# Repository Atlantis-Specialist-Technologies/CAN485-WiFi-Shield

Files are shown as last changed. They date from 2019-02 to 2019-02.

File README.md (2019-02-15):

SparkFun AST-CAN485 WiFi Shield
========================================

SparkFun AST-CAN485 WiFi Shield

[*SparkFun AST-CAN485 WiFi Shield (14597)*](https://www.sparkfun.com/products/14597)

The [AST-CAN485 Dev Board](https://www.sparkfun.com/products/14483) brings CAN (Control Area Network) and RS485 to a small, Pro Mini form factor with the ability to interface to 24V input and outputs. When looking to save space, losing the communication cable is one of the best options as well. The SparkFun AST-CAN485 WiFi Shield does just that. With Screw terminal connectors for RS-485 and a U.FL connector, this board supplies solid solutions for working wirelessly in automation, an environment famous for being noisy and unforgiving to electronics. 

The board uses Espressif's ESP8266, a widely used chip in IoT, for wireless communication. The AST-CAN485 WiFi Shield possesses a PCB trace antenna as well as an on-board U.FL connector which allows for external WiFi antennas in situations where more signal strength or distance is needed. An FTDI header is provided as well for working with the ESP8266.

Repository Contents
-------------------

* **/Documentation** - Data sheets, additional product information
* **/Examples/BasicSerial** - Enclosure files 
* **/Hardware** - Eagle design files (.brd, .sch)

Documentation
--------------
* **[Hookup Guide](https://learn.sparkfun.com/tutorials/ast-can485-wifi-shield-hookup-guide)** - Basic hookup guide for the SparkFun AST-CAN485 WiFi Shield.
* **[SparkFun Fritzing repo](https://github.com/sparkfun/Fritzing_Parts)** - Fritzing diagrams for SparkFun products.

License Information
-------------------

This product is _**open source**_! 

Please review the LICENSE.md file for license information. 

If you have any questions or concerns on licensing, please contact techsupport@sparkfun.com.

Distributed as-is; no warranty is given.

- Your friends at SparkFun, in collaboration with Atlantis Specialist Technologies

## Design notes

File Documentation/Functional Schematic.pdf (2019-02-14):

CAN485

AT90CAN128 | ESP8266 Level Shift | SW²

TX
TX | RX

RX

Serial 0

TX

RX

Serial 1

RS 485
Transceiver
RS485
SPI | SPI
D6 | ESP RST

Wifi Shield

3.3V FTDI

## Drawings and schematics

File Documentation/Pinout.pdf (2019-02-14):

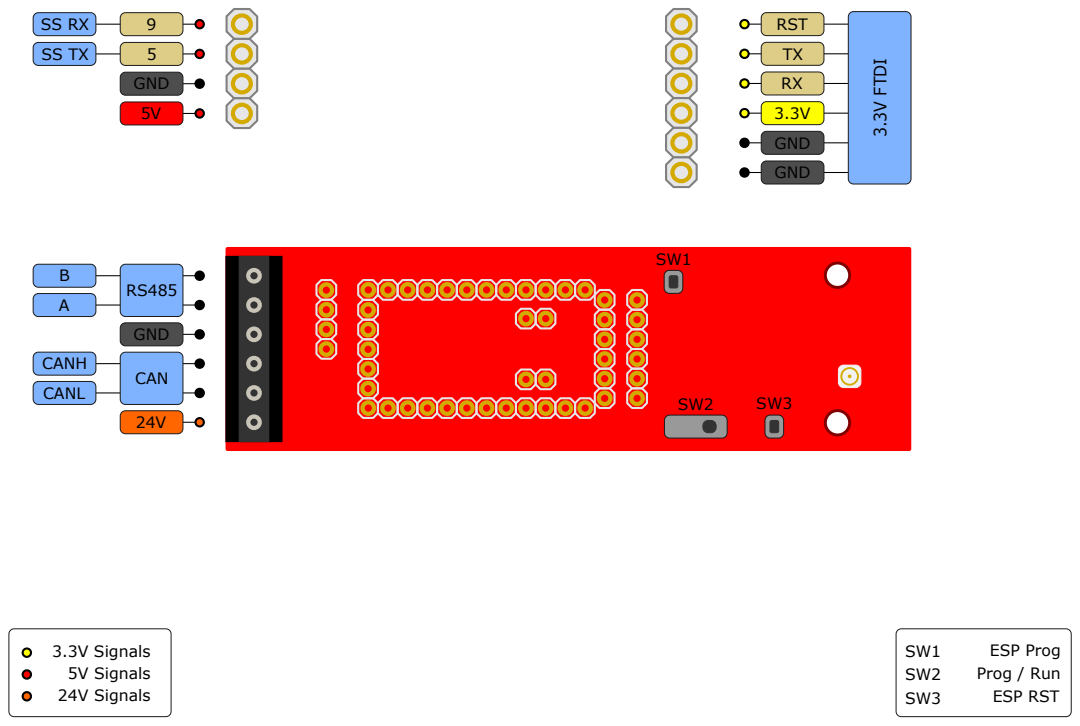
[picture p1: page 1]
GND; CAN; CANL; CANH AB; RST; 3.3V FTDI; 5V Signals 24V Signals; 3.3V Signals; Prog / Run ESP RST; ESP Prog

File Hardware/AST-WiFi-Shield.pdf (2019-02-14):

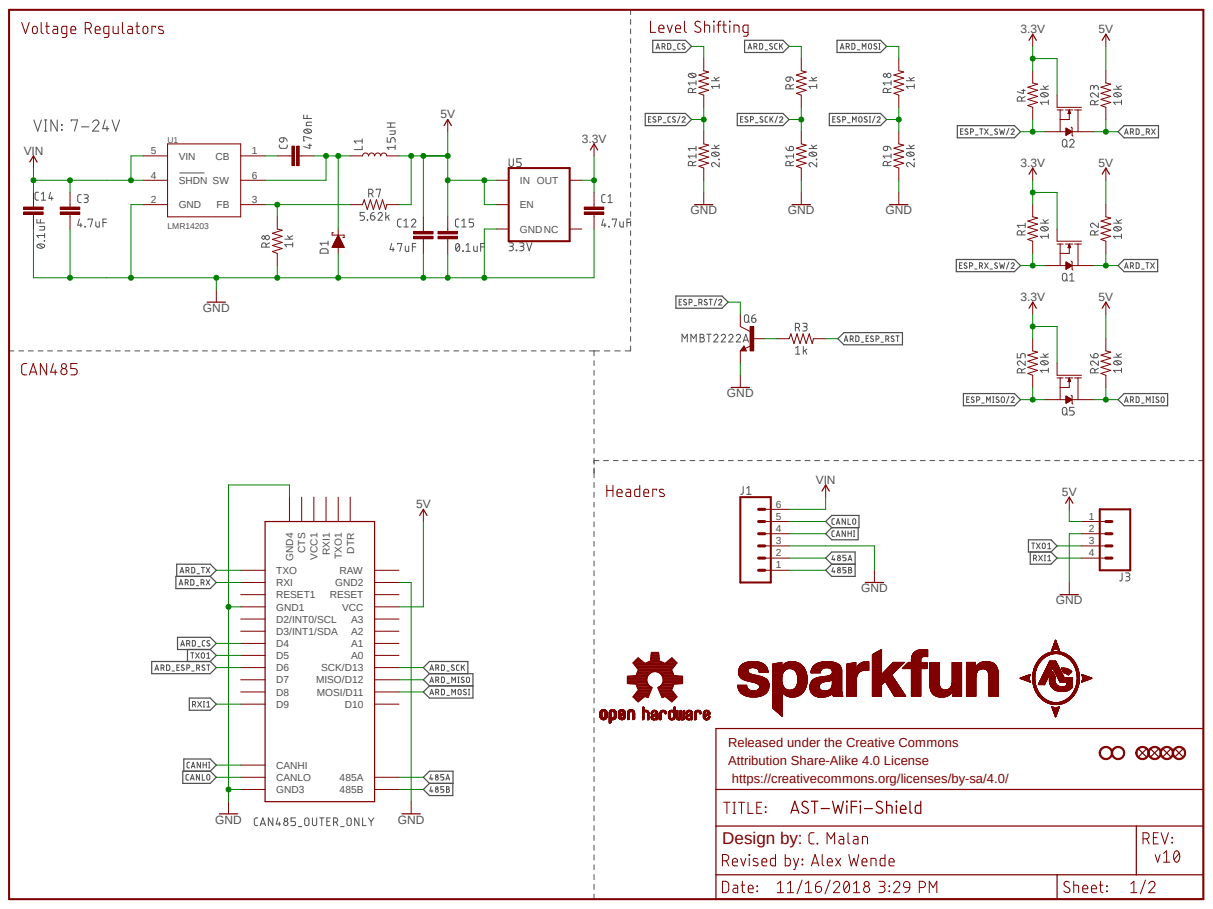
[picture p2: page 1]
LMR14203 U1; GND; VIN; 3 GND 2; SHDN 4; 6 VIN 5; INGNDOUT EN; A0A1A2A3 CANHI CANLOCTS D2/INT0/SCL D3/INT1/SDA D4 D5 D6 D7 D8 D9; D10DTR GND1; GND2 GND3GND⁴; MISO/D12 MOSI/D11 RAW; RESET1; RESET RXI; RXI1 SCK/D13 TXO; TXO¹ VCC VCC¹; Design by:

6 Released under the Creative Commons

Attribution Share-Alike 4.0 License
https://creativecommons.org/licenses/by-sa/4.0/

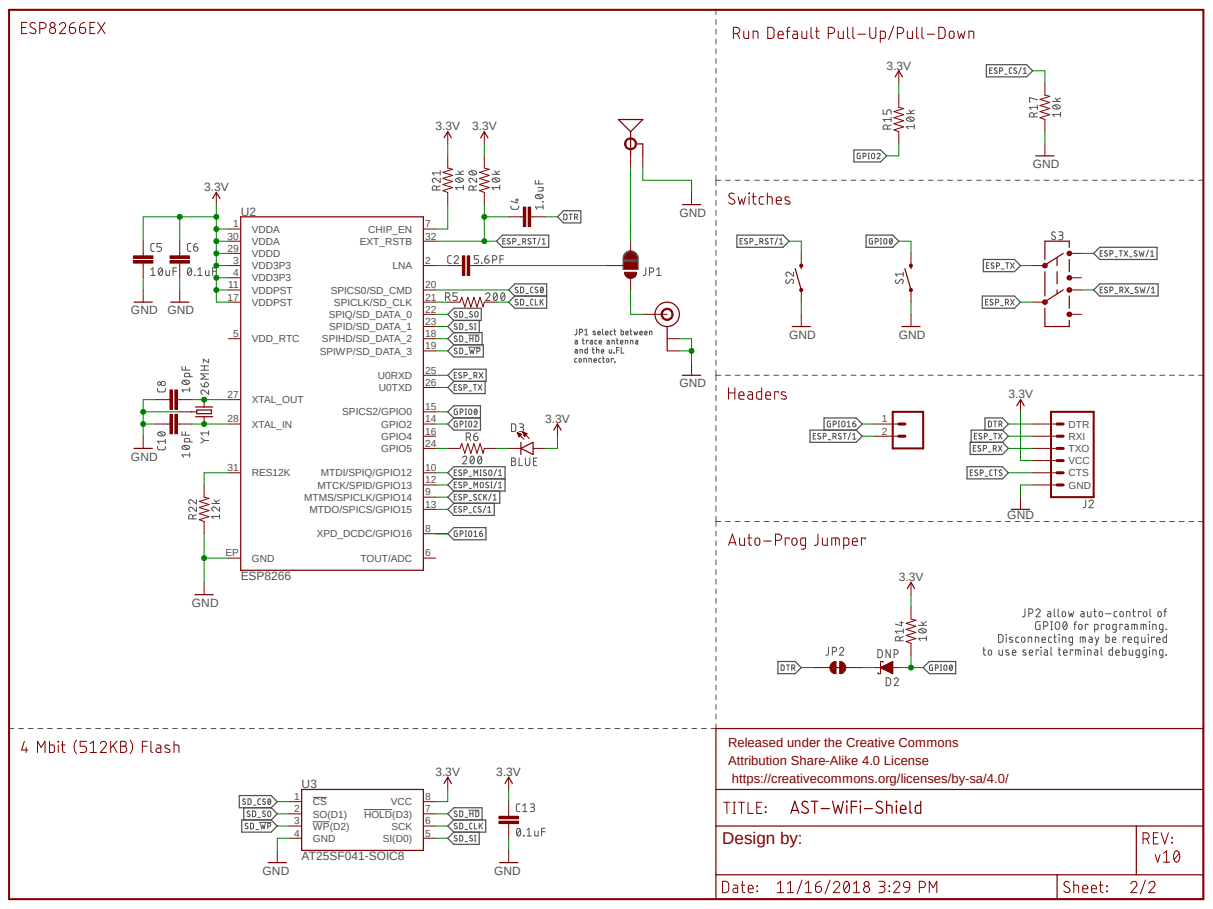
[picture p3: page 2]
ESP8266; GND; GND GND; AT25SF041-SOIC8; VDDA 1; LNA; 2 VDD3P3 3; VDD3P3 4; VDD_RTC 5; TOUT/ADC; CHIP_EN; XPD_DCDC/GPIO16; 8 MTMS/SPICLK/GPIO14; 9 MTDI/SPIQ/GPIO12; 10 VDDPST 11; MTCK/SPID/GPIO13; 12 MTDO/SPICS/GPIO15; 13 GPIO2; 14 SPICS2/GPIO0; 15 GPIO4; 16 VDDPST 17; SPIHD/SD_DATA_2; 18 SPIWP/SD_DATA_3; 19 SPICS0/SD_CMD; 20 SPICLK/SD_CLK; 21 SPIQ/SD_DATA_0; 22 SPID/SD_DATA_1; 23 GPIO5; 24 U0RXD; 25 U0TXD; 26 XTAL_OUT 27; XTAL_IN 28; VDDD 29; VDDA 30; RES12K 31; EXT_RSTB; 32 GND EP; GND 4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

Released under the Creative Commons
Attribution Share-Alike 4.0 License
https://creativecommons.org/licenses/by-sa/4.0/

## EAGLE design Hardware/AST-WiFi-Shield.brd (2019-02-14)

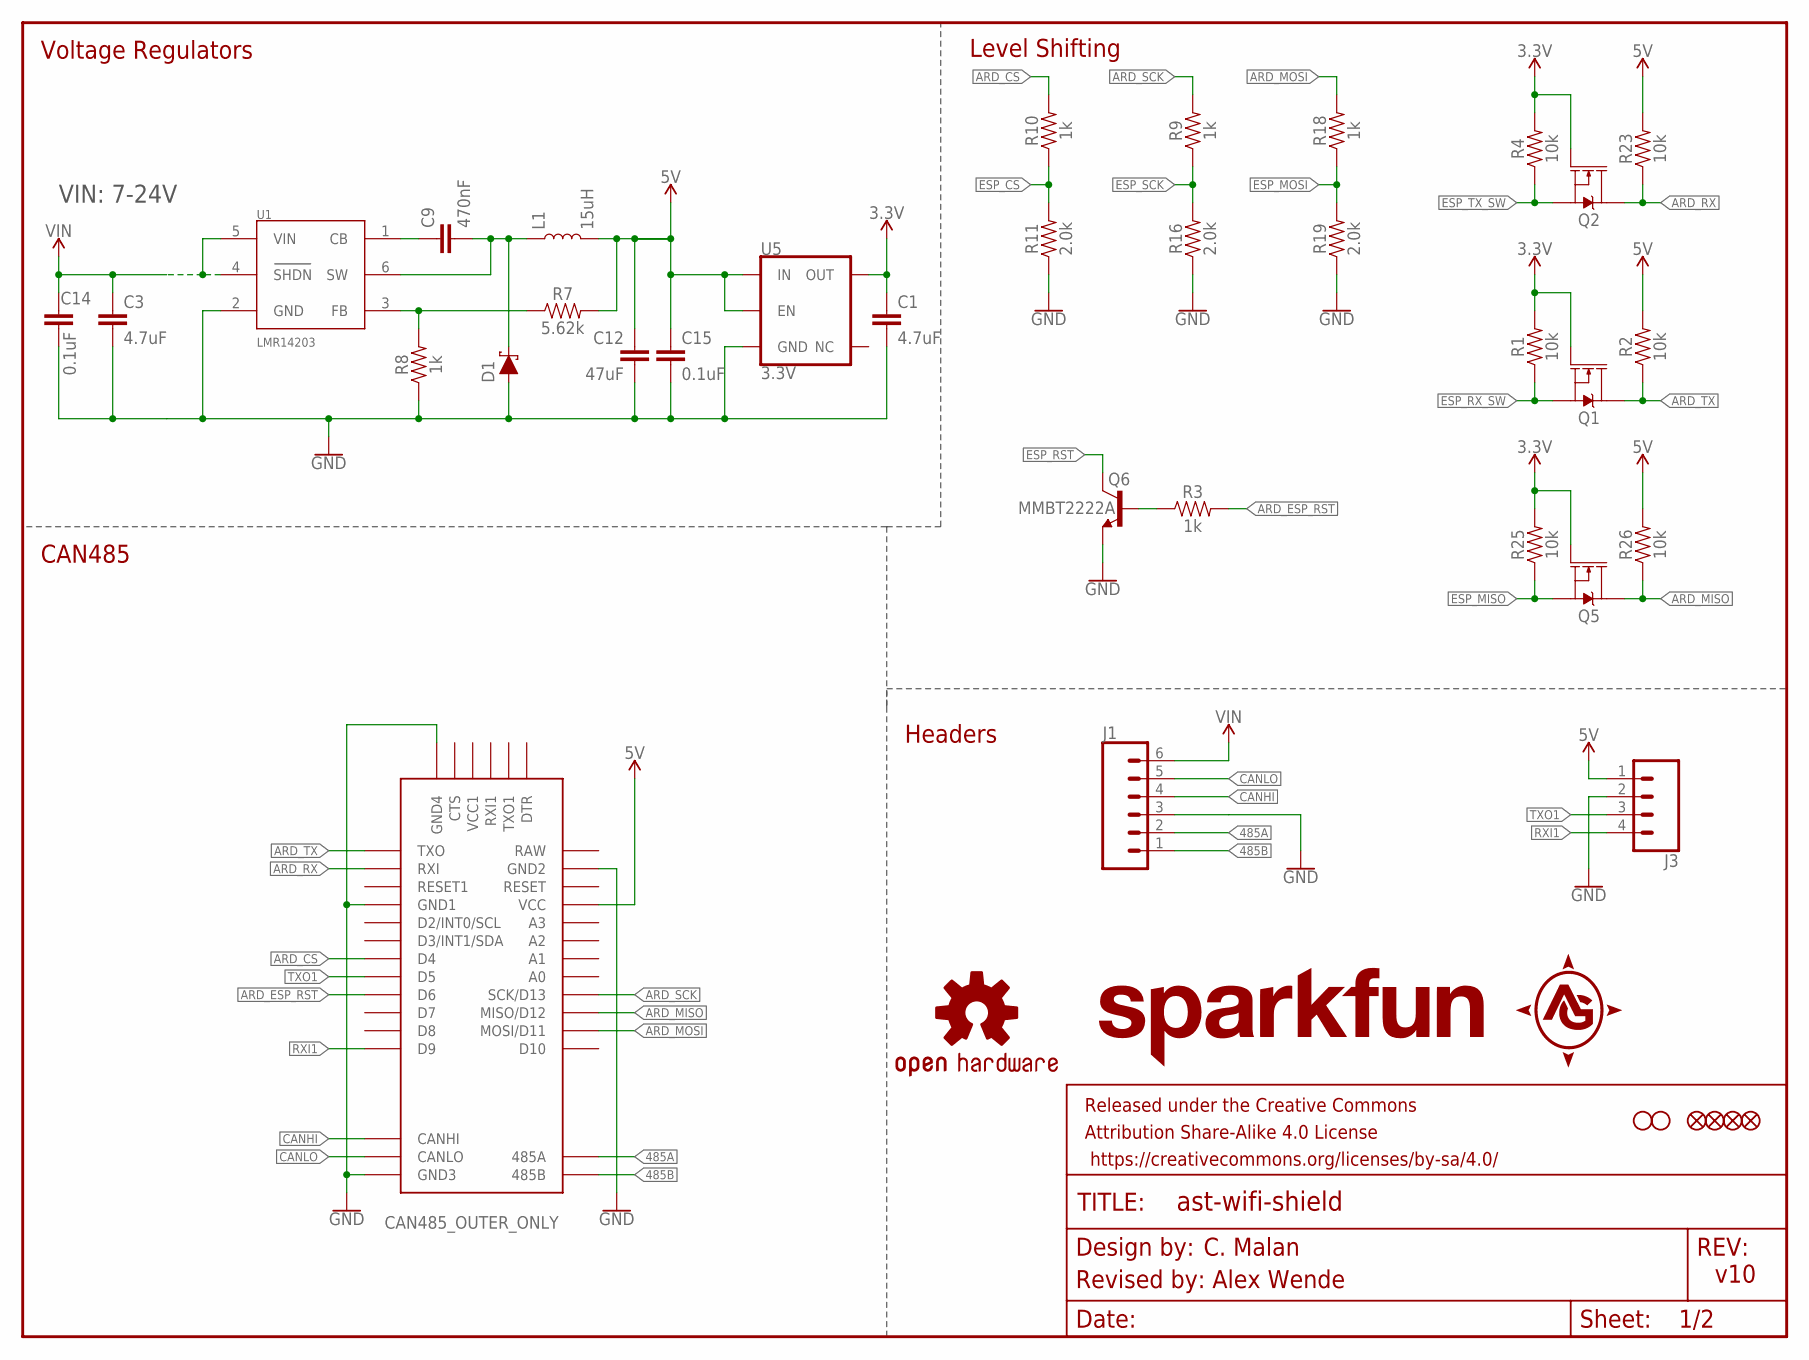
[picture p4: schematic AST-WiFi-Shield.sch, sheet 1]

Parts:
C1, C3: 4.7uF; 0603
C9: 470nF; 0603
C12: 47uF; 0805
C14, C15: 0.1uF; 0603
D1: DIODE-SCHOTTKY-MSS1P6-M3/89A; DIODE-MICRO-SMP
FD1, FD2, FD3, FD4: FIDUCIALUFIDUCIAL; FIDUCIAL-MICRO
FRAME2: FRAME-LETTER; CREATIVE_COMMONS
H1, H2: STAND-OFF
J1: CONN_063.5MM-6; SCREWTERMINAL-3.5MM-6
J3: CONN_04LOCK; 1X04_LOCK
L1: 15uH; INDUCTOR_LQH32
LOGO1: OSHW-LOGOS; OSHW-LOGO-S
LOGO2: SFE_LOGO_NAME.2_INCH; SFE_LOGO_NAME_.2
Q1, Q2, Q5: 220mA/50V/3.5Ω; SOT23-3
Q6: MMBT2222A; SOT23-3@1
R1, R2, R4, R23, R25, R26: 10k; 0603
R3, R8, R9, R10, R18: 1k; 0603
R7: 5.62k; 0603
R11, R16, R19: 2.0k; 0603
U1: LMR14203; SOT23-6
U5: 3.3V; SOT23-5
U$2: CAN485_OUTER_ONLY

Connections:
3.3V: C1.1, Q1.1 (G), Q2.1 (G), Q5.1 (G), R1.2, R4.2, R25.2, U5.5 (OUT); also elsewhere on the board
5V: C12.1, C15.1, J3.1, L1.P$2 (2), R2.2, R7.2, R23.2, R26.2, U5.1 (IN), U5.3 (EN), U$2.VCC
485A: J1.2, U$2.485A
485B: J1.1, U$2.485B
ARD_CS: R10.2, U$2.4 (D4)
ARD_ESP_RST: R3.2, U$2.6 (D6)
ARD_MISO: Q5.3 (D), R26.1, U$2.12 (MISO/D12)
ARD_MOSI: R18.2, U$2.11 (MOSI/D11)
ARD_RX: Q2.3 (D), R23.1, U$2.RXI
ARD_SCK: R9.2, U$2.13 (SCK/D13)
ARD_TX: Q1.3 (D), R2.1, U$2.TXO
CANHI: J1.4, U$2.CANHI
CANLO: J1.5, U$2.CANLO
ESP_CS: R10.1, R11.2; also elsewhere on the board
ESP_MISO: Q5.2 (S), R25.1; also elsewhere on the board
ESP_MOSI: R18.1, R19.2; also elsewhere on the board
ESP_RST: Q6.3 (C); also elsewhere on the board
ESP_RX_SW: Q1.2 (S), R1.1; also elsewhere on the board
ESP_SCK: R9.1, R16.2; also elsewhere on the board
ESP_TX_SW: Q2.2 (S), R4.1; also elsewhere on the board
GND: C1.2, C3.2, C12.2, C14.2, C15.2, D1.A, J1.3, J3.2, Q6.2 (E), R8.1, R11.1, R16.1, R19.1, U1.2 (GND), U5.2 (GND), U$2.GND1, U$2.GND2, U$2.GND3, U$2.GND4; also elsewhere on the board
unnamed: C9.1, U1.1 (CB)
unnamed: R7.1, R8.2, U1.3 (FB)
unnamed: Q6.1 (B), R3.1
RXI1: J3.4, U$2.9 (D9)
TXO1: J3.3, U$2.5 (D5)
VIN: C3.1, C14.1, J1.6, U1.4 (SHDN), U1.5 (VIN)
VSW: C9.2, D1.C, L1.P$1 (1), U1.6 (SW)

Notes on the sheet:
Headers
Voltage Regulators
Level Shifting
C. Malan
Revised by: Alex Wende
CAN485
v10
VIN: 7-24V

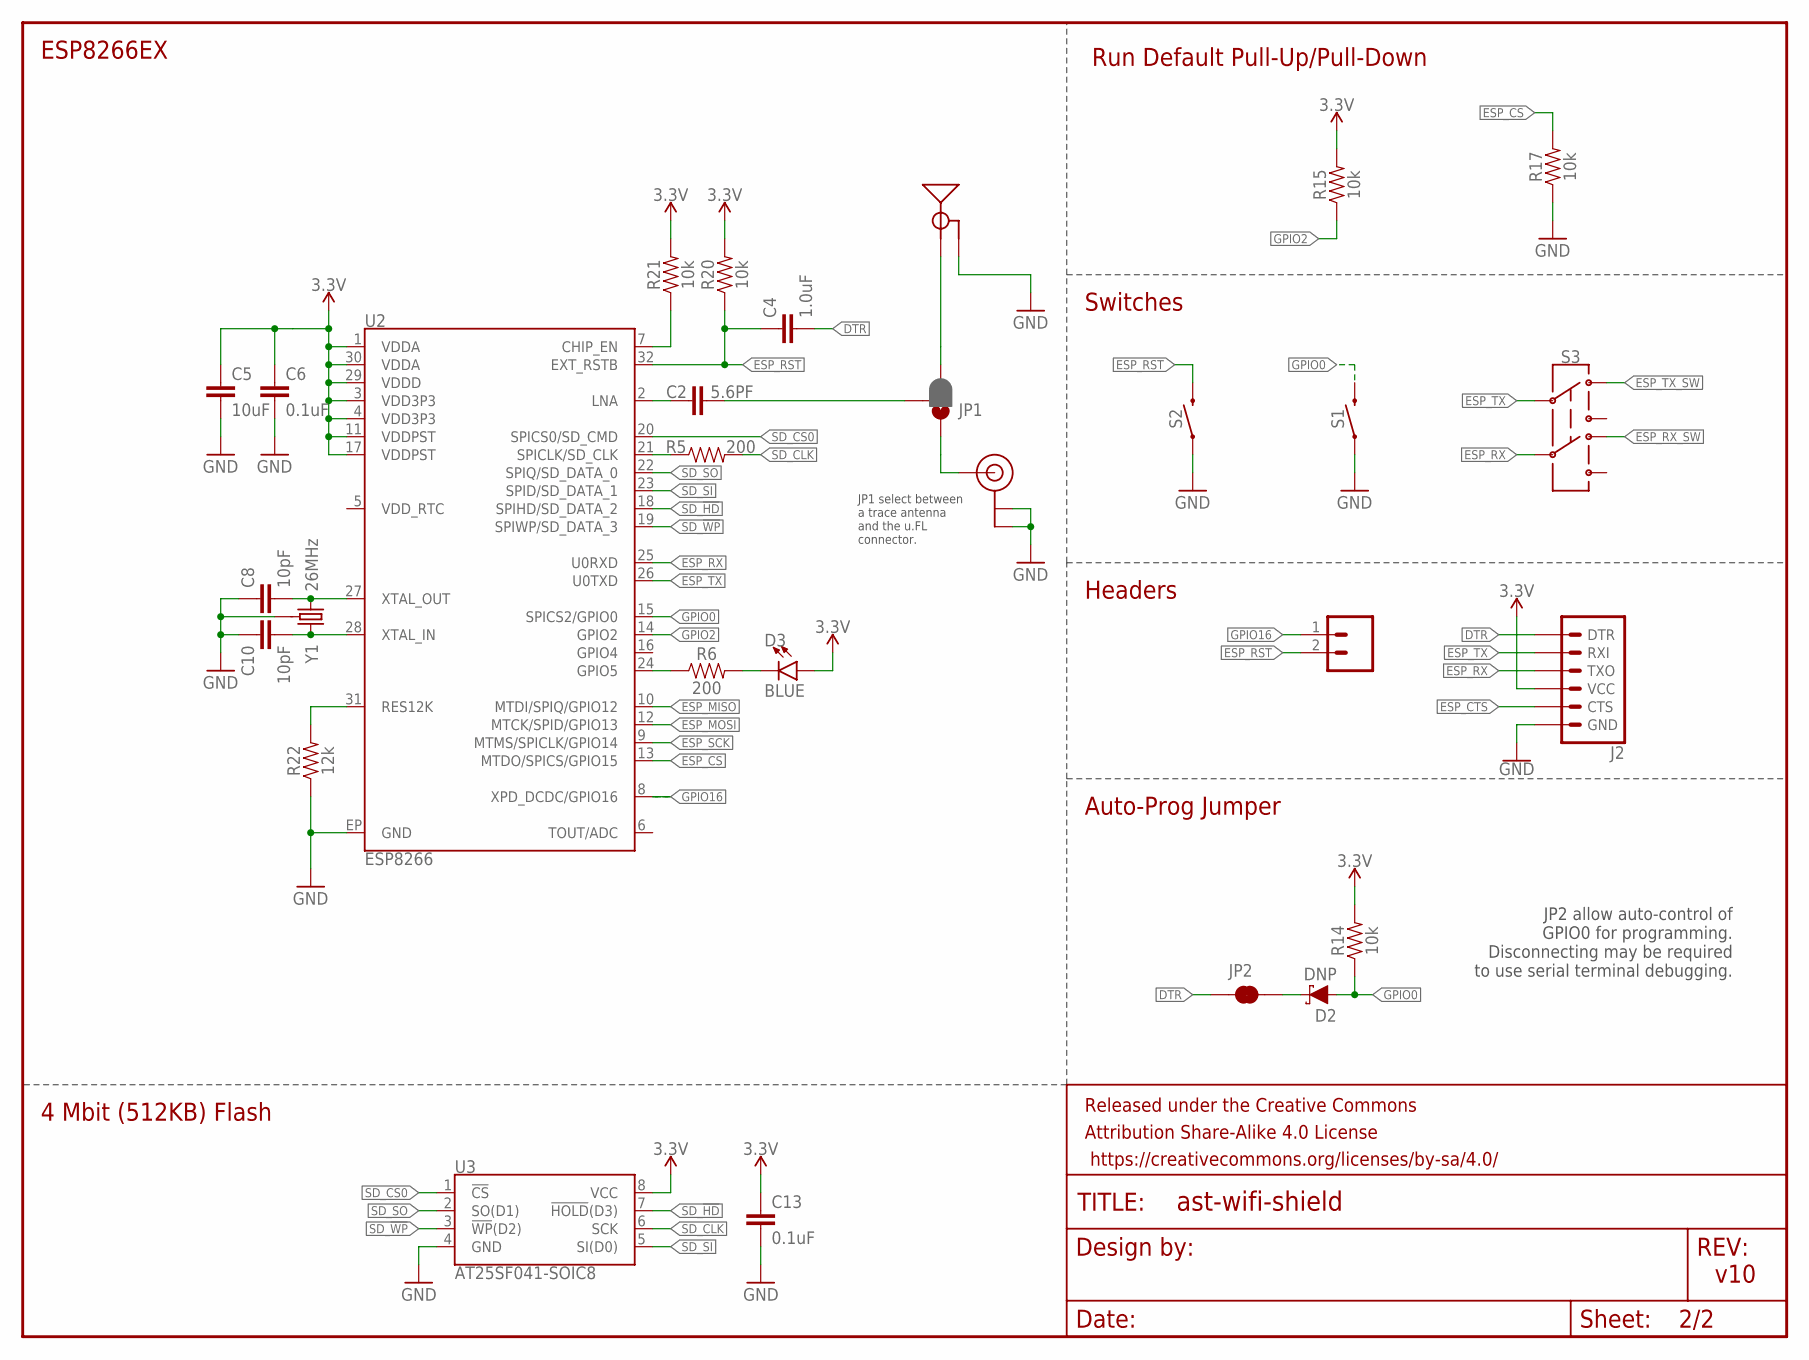
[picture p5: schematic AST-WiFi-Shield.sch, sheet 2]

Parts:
C2: 5.6PF; 0603
C4: 1.0uF; 0603
C5: 10uF; 0603
C6, C13: 0.1uF; 0603
C8, C10: 10pF; 0603
D2: DNP; SOD-323
D3: BLUE; LED-0603
E1: ANTENNATRACE; TRACE_ANTENNA_2.4GHZ_25.7MM
E2: U.FL
FRAME3: FRAME-LETTERNO_PACKAGE; DUMMY
J2: 6_PIN_SERIAL_TARGETLOCK; 1X06_LOCK
JP1: JUMPER-SMT_3_1-NC_PASTE_NO-SILK; SMT-JUMPER_3_1-NC_PASTE_NO-SILK
JP2: JUMPER-SMT_2_NC_TRACE_NO-SILK; SMT-JUMPER_2_NC_TRACE_NO-SILK
R5, R6: 200; 0603
R14, R15, R17, R20, R21: 10k; 0603
R22: 12k; 0603
S1, S2: MOMENTARY-SWITCH-SPST-SMD-4.6X2.8MM; TACTILE_SWITCH_SMD_4.6X2.8MM
S3: SWITCH-DPDT-SMD-JS202011JCQN; SWITCH_DPDT_SMD_JS202011JCQN
SJ2: SLEEP-PTH; 1X02_NO_SILK
U2: ESP8266; QFN32
U3: AT25SF041-SOIC8; SO08
Y1: 26MHz; CRYSTAL-SMD-3.2X2.5

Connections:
3.3V: C5.1, C6.1, C13.1, D3.A, J2.4 (VCC), R14.2, R15.2, R20.2, R21.2, U2.1 (VDDA), U2.3 (VDD3P3), U2.4 (VDD3P3), U2.11 (VDDPST), U2.17 (VDDPST), U2.29 (VDDD), U2.30 (VDDA), U3.8 (VCC); also elsewhere on the board
ANT: E2.FEED (SIGNAL), JP1.1
CHIP_EN: R21.1, U2.7 (CHIP_EN)
DTR: C4.2, J2.1 (DTR), JP2.1
ESP_CS: R17.2, U2.13 (MTDO/SPICS/GPIO15); also elsewhere on the board
ESP_CTS: J2.5 (CTS)
ESP_MISO: U2.10 (MTDI/SPIQ/GPIO12); also elsewhere on the board
ESP_MOSI: U2.12 (MTCK/SPID/GPIO13); also elsewhere on the board
ESP_RST: C4.1, R20.1, S2.3 (2), S2.4 (2), SJ2.2, U2.32 (EXT_RSTB); also elsewhere on the board
ESP_RX: J2.3 (TXO), S3.5, U2.25 (U0RXD)
ESP_RX_SW: S3.6 (4); also elsewhere on the board
ESP_SCK: U2.9 (MTMS/SPICLK/GPIO14); also elsewhere on the board
ESP_TX: J2.2 (RXI), S3.2, U2.26 (U0TXD)
ESP_TX_SW: S3.1; also elsewhere on the board
GND: C5.2, C6.2, C8.1, C10.1, C13.2, E1.GND, E1.GND2 (GND), E2.1 (GND), E2.2 (GND), J2.6 (GND), R17.1, R22.1, S1.1, S1.2 (1), S2.1, S2.2 (1), U2.EP (GND), U3.4 (GND), Y1.2 (GND), Y1.4 (GND); also elsewhere on the board
GPIO0: D2.A, R14.1, S1.3 (2), S1.4 (2), U2.15 (SPICS2/GPIO0)
GPIO2: R15.1, U2.14 (GPIO2)
GPIO5: R6.1, U2.24 (GPIO5)
GPIO16: SJ2.1, U2.8 (XPD_DCDC/GPIO16)
unnamed: D2.C, JP2.2
unnamed: R22.2, U2.31 (RES12K)
unnamed: C10.2, U2.28 (XTAL_IN), Y1.3 (2)
unnamed: C8.2, U2.27 (XTAL_OUT), Y1.1
unnamed: C2.1, U2.2 (LNA)
unnamed: C2.2, JP1.2
unnamed: D3.C, R6.2
SD_!HD!: U2.18 (SPIHD/SD_DATA_2), U3.7 (!HOLD!(D3))
SD_!WP!: U2.19 (SPIWP/SD_DATA_3), U3.3 (!WP!(D2))
SD_CLK: R5.2, U3.6 (SCK)
SD_CLK0: R5.1, U2.21 (SPICLK/SD_CLK)
SD_CS0: U2.20 (SPICS0/SD_CMD), U3.1 (!CS!)
SD_SI: U2.23 (SPID/SD_DATA_1), U3.5 (SI(D0))
SD_SO: U2.22 (SPIQ/SD_DATA_0), U3.2 (SO(D1))
TRACE_ANT: E1.ANT (SIGNAL), JP1.3

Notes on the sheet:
JP1 select between a trace antenna and the u.FL connector.
ESP8266EX
Auto-Prog Jumper
Run Default Pull-Up/Pull-Down
4 Mbit (512KB) Flash
Headers
Switches
v10
JP2 allow auto-control of GPIO0 for programming. Disconnecting may be required to use serial terminal debugging.

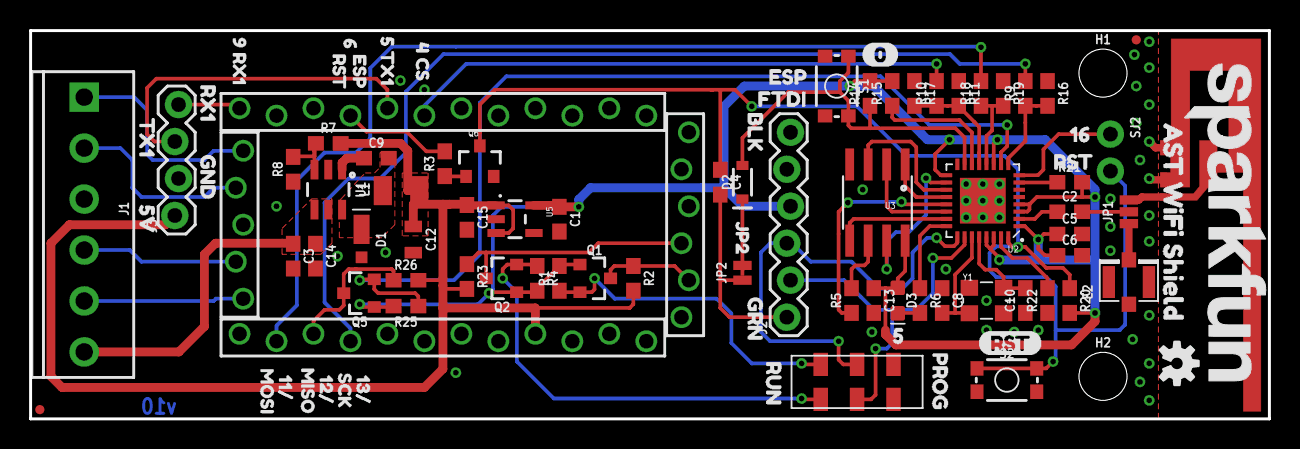
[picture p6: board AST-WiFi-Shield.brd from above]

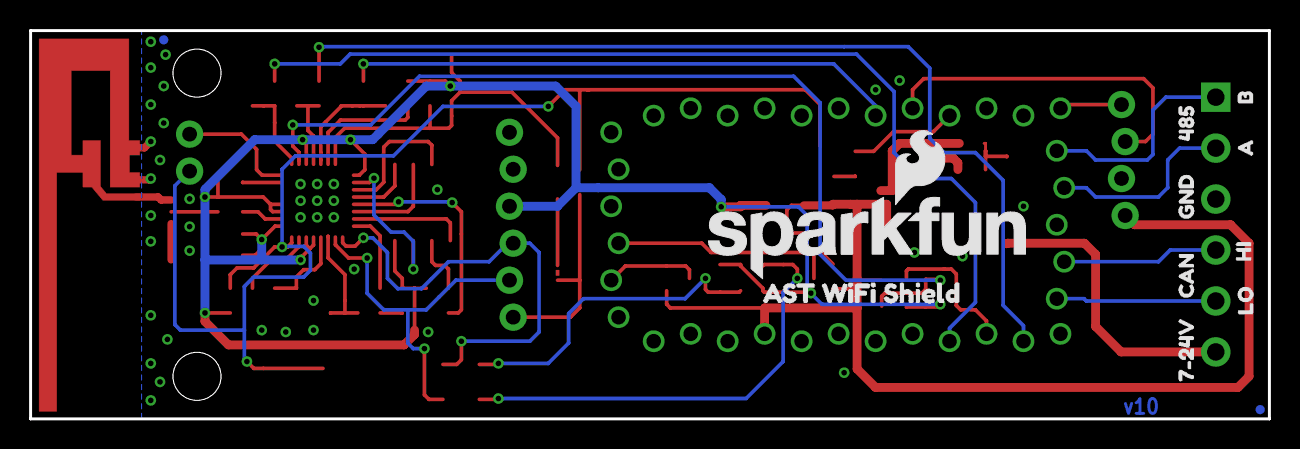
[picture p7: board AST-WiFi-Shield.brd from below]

Board: 2 copper layers, 85.1 x 26.7 mm, 110 parts (12 on the bottom side), 52 nets.

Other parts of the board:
U$1: _9_RX12
U$3: 5_TX11
U$4: 612
U$5: _ESP4
U$6: _RST5
U$7: 7#24V0
U$8: GRN2
U$9: BLK3
U$10: _MOSI7
U$11: 12#1
U$12: 13#2
U$13: RX14
U$14: TX15
U$15: GND6
U$16: 5V7
U$17: 00
U$18: RST1
U$19: MISO8
U$20: SCK11
U$21: GND10
U$22: CAN11
U$23: HI26
U$24: LO27
U$25: 48518
U$27: JP23
U$28: 11#0
U$29: A33
U$30: B34
U$32, U$35: AST_WIFI_SHIELD0
U$33: SFE_LOGO_NAME_FLAME_.2
U$36: FTDI7
U$37: 168
U$38: ESP22
U$39: RST23
U$40: 52
U$41: RUN1
U$42: PROG0
U$43: 4_CS0

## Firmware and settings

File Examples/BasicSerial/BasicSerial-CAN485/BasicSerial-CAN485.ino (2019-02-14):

/*
 * Serial communications example
 * Allows the CAN485 built-in LED to be controlled over the serial port
 * If an 'h' is received, the LED is switched on. If anything else is received it is switched off.
 * 
 * Sends alternating x and h over the serial port.
 */

#define BLINK_DELAY 100

char serialIn;
bool blinkState = false;
unsigned long prevTime = 0;

void setup() {
  Serial.begin(115200);
  pinMode(LED_BUILTIN, OUTPUT);
  prevTime = millis();
}

void loop() {
  // Read any serial input and set the LED accordingly
  if (Serial.available()>0){
    serialIn = Serial.read();
    if (serialIn == 'h'){
      digitalWrite(LED_BUILTIN, HIGH);                  // Set LED on
    }
    else if((serialIn == '\n')||(serialIn == '\r')){    // Ignore newline or carriage return
      
    }
    else
    {
      digitalWrite(LED_BUILTIN, LOW);                   // Set LED off
    }
  }

  // non blocking timed serial send
  // Every BLINK_DELAY, a character is sent over the serial port
  if ((millis() - prevTime) > BLINK_DELAY){
    prevTime = millis();
    if (blinkState){
      Serial.print('h');
      blinkState = false;
    }
    else{
      Serial.print('x');
      blinkState = true;
    }
  }
}

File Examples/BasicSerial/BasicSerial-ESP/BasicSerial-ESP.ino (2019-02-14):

/*
 * Serial communications example
 * Allows the ESP built-in LED to be controlled over the serial port
 * If an 'h' is received, the LED is switched on. If anything else is received it is switched off.
 * Also echos any received serial input over the serial port
 */

char serialIn;

void setup() {
  Serial.begin(115200);
  pinMode(LED_BUILTIN, OUTPUT);
}

void loop() {
  if (Serial.available()>0){
    serialIn = Serial.read();
    Serial.print(serialIn);
    if (serialIn == 'h'){
      digitalWrite(LED_BUILTIN, LOW);                   // Set LED on (ESP LED has inverted logic)
    }
    else if((serialIn == '\n')||(serialIn == '\r')){    // Ignore newline or carriage return
      
    }
    else
    {
      digitalWrite(LED_BUILTIN, HIGH);                  // Set LED off (ESP LED has inverted logic)
    }
  }
}

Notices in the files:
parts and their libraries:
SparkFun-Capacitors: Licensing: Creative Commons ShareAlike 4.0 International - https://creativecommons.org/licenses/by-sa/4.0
